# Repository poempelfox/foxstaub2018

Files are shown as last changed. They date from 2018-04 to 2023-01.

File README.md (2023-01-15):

# FoxStaub 2018 - 2022 edition

(FIXME: add picture)

## Introduction

This is a solar powered air quality (fine particles) sensor based on an SDS011
particulate matter (PM) sensor. It also features a BME280 sensor for
measuring temperature, humidity and barometric pressure. An
Adafruit 32U4 RFM69HCW with 868 MHz radio is used as the main microcontroller,
and transmits the measured data wirelessly. The radio-transmitted measurements
are then received by a [Jeelink V3](https://jeelabs.net/projects/hardware/wiki/JeeLink)
and fed into [FHEM](https://fhem.de/).

This project was of course inspired by [https://luftdaten.info](luftdaten.info),
a project for the crowd-sourcing of open sensor data originating in the city of
Stuttgart, which does due to its geography have a very high fine particle
pollution.

## Part list / BOM

* Adafruit Feather 32U4 RFM69HCW (868 MHz variant)
* Adafruit SHT31 (temperature/humidity sensor) breakout
* ClosedCube LPS25HB (pressure sensor) breakout
* Note that the original version of this, built in 2018, used a BME280 instead of the SHT31 and the LPS25HB. After two of these died within just 5 years (after reporting utter nonsense in the weeks or months before), I have decided these are not suitable sensors, and replaced them.
* SDS011 air quality sensor
* JST XH 7pin plug to connect the SDS011.  
  I used Voelkner #D17687 (as the hull of the plug) and #D16379 (as the pins
  inside), and this is the proper plug to use, but alternatively, you should be
  just fine with using normal jumper wire connectors.
* Two "Marley HT" pipe bends are used as the case, as in the luftdaten.info project.  
  However, the DN75 size they recommend wasn't available, so I used DN90 instead.
* 12V AGM battery for storing the power. I originally used a "Offgridtec AGM Solar
  Batterie extrem zyklenfest 12 Ah 12V" off Amazon, but this proved to be too small
  for the winter, always running out of power around December. This has been upgraded
  to a 32 Ah battery in January 2023, we'll see how that one works out.
* (5m) Micro USB power cable for getting the power from the battery to the sensor
* solar charge controller with USB output (I used a "LS0512EU 5A" off Amazon)
* a solar panel big enough to charge the battery even when it's not sunny (I  
  used a "Suaoki Solar Autobatterie Panel Ladegeraet 18W 18V" off Amazon. This  
  is a thin, bendable module that I mounted onto a wooden board for stability.)
* (5m) cable for connecting the solar panel to the charge controller
* fuse to prevent short circuits from making things go up in smoke

## Power

Sadly, the SDS011 uses a lot of power while measuring, the data sheet claims
up to 80 mA. That makes powering this with solar power a challenge, even if it
does not measure continuously (it measures for 30 seconds before going to sleep
for 120 seconds because that increases the sensor life) and actual consumption
seems to be less than what the datasheet claims.

The microcontroller-board actually would have a LiPo charger circuit onboard,
so you could just connect a somewhat large LiPo battery and be done with it
(you'd need to generate the 5V for the SDS011 through a boost converter from
the microcontroller-boards 3.3V output though).
However, I did not like the idea of putting a temperamental LiPo battery into a
tiny case that can heat to 50+ degrees when hit by the sun, and cool below -20
in winter. Instead, the plan was to use a "Goal Zero Guide 10 Plus" power bank
with four NiMH batteries for storing the power. However, it turned out to be
impossible to find any 6V solar panel that would be big enough to charge that
power bank and rigid enough to be mounted on my balcony. It seems solar panels
only come in two flavours: 6V and utter crap (mechanically), or 12+V.

So sadly, instead of the nice and compact power bank,
I had to use a 12V AGM battery and matching solar charge controller with
USB output. These parts are not right where the sensor and the solar panel are,
but instead they're connected by 5 meters of cable and stored safely in the
closet adjacent to my balcony where they are protected from the weather.

## Wireless protocol

Data is sent on 868,300 MHz with FSK modulation and a bitrate of 17241 baud.
On a higher level, the protocol we use is that of a "CustomSensor" from the
FHEM LaCrosseItPlusReader sketch for the Jeelink. However, support for that
if not compiled in by default, so you will have to enable it in the source
code, then recompile the sketch and flash the result onto your Jeelink.

The file `36_Foxstaub2018viaJeelink.pm` in this repository contains the
FHEM module for receiving the sensor. To use it, you will need to put this
file into /opt/fhem/FHEM/ and then modify the file 36_JeeLink.pm: to the
string `clientsJeeLink` append `:Foxstaub2018viaJeelink`.

The format of the packets we send is this:

| Byte | Content description |
| ---: | ---|
| (-)  | Preamble: 3 times 0xAA (you usually don't see these bytes anywhere) |
| (-)  | Sync-Bytes (2): 0x2D 0xD4 |
| 0  | Startbyte (=0xCC) |
| 1  | Sensor-ID (in the range 0 - 255/0xff) |
| 2  | Number of data bytes that follow (13) |
| 3  | Sensortype (=0xf5 for FoxStaub) |
| 4  | Pressure, MSB. Raw value from LPS25HB. |
| 5  | Pressure cont. |
| 6  | Pressure, LSB |
| 7  | Temperature, MSB.  Raw value from SHT31. Formula for converting to degree celsius (value / 65535) * 175 - 45 |
| 8  | Temperature, LSB |
| 9  | rel.Humidity, MSB.  Raw value from SHT31. 0 == 0%, 65535 == 100% |
|  10  | rel.Humidity, LSB |
|  11  | PM2.5, MSB.  Particulate Matter 2.5u is in 1/10th ug/m^3 |
|  12  | PM2.5, LSB |
|  13  | PM10, MSB.  Particulate Matter 10u is in 1/10th ug/m^3 |
|  14  | PM10, LSB |
|  15  | Battery voltage. This is measured through a voltage divider, with 1 MOhm towards GND, and 10 MOhm towards '+'. The ADC runs with a reference voltage of 2.56 volts, meaning 255 would be 2.56 volts, thus the formula for converting this value into volts is: value * 0.11 |
|  16  | CRC |

## Compile error

Compilation of console.c will fail when using an avr-gcc version between
4.8 and 6.4 (inclusive) due to a compiler bug. avr-gcc will die with the
error message `internal compiler error: in push_reload, at reload.c:1360`.
As a workaround, you can add `-fno-move-loop-invariants` to the compiler
flags. Using this just for console.c is enough, for the rest of the source gcc
does not need this workaround.

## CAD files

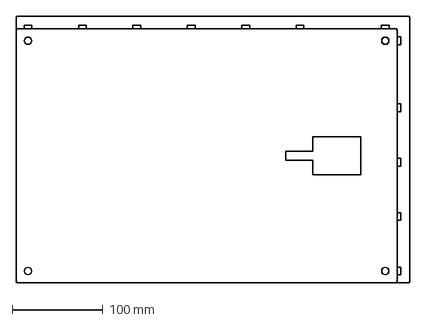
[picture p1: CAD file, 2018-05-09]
solarpanel/solarpanelholder.dxf
434.0 x 294.0 mm

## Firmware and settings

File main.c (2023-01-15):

/* $Id: main.c $
 * main for foxstaub2018 (Foxis Feinstaubsensor)
 * (C) Michael "Fox" Meier 2018
 */

#include <avr/io.h>
#include <avr/interrupt.h>
#include <avr/wdt.h>
#include <avr/eeprom.h>
#include <avr/power.h>
#include <avr/sleep.h>
#include <stdio.h>
#include <string.h>
#include <util/delay.h>

#include "adc.h"
#include "eeprom.h"
#include "lps25hb.h"
#include "lufa/console.h"
#include "rfm69.h"
#include "sds011.h"
#include "sht3x.h"
#include "timers.h"

/* The values last measured */
/* How often did we send a packet? */
uint32_t pktssent = 0;
/* Pressure, in (Pascal * 256) */
uint32_t pressure = 0;
/* Temperature, in (degC * 100) */
int32_t temperature = 0;
/* Rel. Humidity, in (% * 512) */
uint16_t humidity = 0;
/* Particulate matter measurements. in (PMn * 10) ug/m^3 */
/* 0xffff marks it as invalid, this value can never be measured as it's far
 * outside the sensors range */
uint16_t particulatematter2_5u = 0xffff;
uint16_t particulatematter10u = 0xffff;
uint8_t batvolt = 0;

/* This is just a fallback value, in case we cannot read this from EEPROM
 * on Boot */
uint8_t sensorid = 3; // 0 - 255 / 0xff

/* The frame we're preparing to send. */
static uint8_t frametosend[17];

/* Length of one SDS011 measurement cycle, in ticks. */
#define SDS011CYCLELENGTH 72 /* 151 seconds */
/* How long do we turn the sensor on at the beginning of the cycle? */
#define SDS011CYCLEONTIME 15 /* 31 seconds */

/* We need to disable the watchdog very early, because it stays active
 * after a reset with a timeout of only 15 ms. */
void dwdtonreset(void) __attribute__((naked)) __attribute__((section(".init3")));
void dwdtonreset(void) {
  MCUSR = 0;
  wdt_disable();
}

static uint8_t calculatecrc(uint8_t * data, uint8_t len)
{
  uint8_t i, j;
  uint8_t res = 0;
  for (j = 0; j < len; j++) {
    uint8_t val = data[j];
    for (i = 0; i < 8; i++) {
      uint8_t tmp = (uint8_t)((res ^ val) & 0x80);
      res <<= 1;
      if (0 != tmp) {
        res ^= 0x31;
      }
      val <<= 1;
    }
  }
  return res;
}

/* Fill the frame to send with our collected data and a CRC.
 * The protocol we use is that of a "CustomSensor" from the
 * FHEM LaCrosseItPlusReader sketch for the Jeelink.
 * So you'll just have to enable the support for CustomSensor in that sketch
 * and flash it onto a JeeNode and voila, you have your receiver.
 *
 * Byte  0: Startbyte (=0xCC)
 * Byte  1: Sensor-ID (0 - 255/0xff)
 * Byte  2: Number of data bytes that follow (13)
 * Byte  3: Sensortype (=0xf5 for FoxStaub)
 * Byte  4: Pressure, MSB    (raw value from LPS25HB)
 * Byte  5: Pressure
 * Byte  6: Pressure, LSB
 * Byte  7: Temperature, MSB   (raw value from SHT31)
 * Byte  8: Temperature, LSB
 * Byte  9: rel.Humidity, MSB  (raw value from SHT31)
 * Byte 10: rel.Humidity, LSB
 * Byte 11: PM2.5, MSB       particulate matter 2.5 is in 1/10th ug/m^3
 * Byte 12: PM2.5, LSB
 * Byte 13: PM10, MSB
 * Byte 14: PM10, LSB
 * Byte 15: battery voltage
 * Byte 16: CRC
 */
void prepareframe(void)
{
  frametosend[ 0] = 0xCC;
  frametosend[ 1] = sensorid;
  frametosend[ 2] = 13; /* 13 bytes of data follow (CRC not counted) */
  frametosend[ 3] = 0xf5; /* Sensor type: FoxStaub */
  frametosend[ 4] = (pressure >> 16) & 0xff;
  frametosend[ 5] = (pressure >>  8) & 0xff;
  frametosend[ 6] = (pressure >>  0) & 0xff;
  frametosend[ 7] = (temperature >> 8) & 0xff;
  frametosend[ 8] = (temperature >> 0) & 0xff;
  frametosend[ 9] = (humidity >> 8) & 0xff;
  frametosend[10] = (humidity >> 0) & 0xff;
  frametosend[11] = (particulatematter2_5u >> 8) & 0xff;
  frametosend[12] = (particulatematter2_5u >> 0) & 0xff;
  frametosend[13] = (particulatematter10u >> 8) & 0xff;
  frametosend[14] = (particulatematter10u >> 0) & 0xff;
  frametosend[15] = batvolt;
  frametosend[16] = calculatecrc(frametosend, 16);
}

void loadsettingsfromeeprom(void)
{
  uint8_t e1 = eeprom_read_byte(&ee_sensorid);
  uint8_t e2 = eeprom_read_byte(&ee_invsensorid);
  if ((e1 ^ 0xff) == e2) { /* OK, the 'checksum' matches. Use this as our ID */
    sensorid = e1;
  }
}

int main(void)
{
  uint16_t lasttxts = 0xf000; /* This forces an update immediately after start */
  uint16_t sds011cyclestart = 0xffff - (SDS011CYCLELENGTH / 2); /* places us at the end of a cycle */
  uint16_t lastloopts = 0;
  uint16_t curts;
  uint16_t tsdiff;
  uint8_t transmitinterval = 15; /* Transmitinterval in ticks of 2.1s, so 15 = 31s */
  
  /* Initialize stuff */
  
  loadsettingsfromeeprom();
  
  adc_init();
  timers_init();
  console_init();
  rfm69_initport();
  /* The RFM69 needs some time to start up (5 ms according to data sheet, we wait 10 to be sure) */
  _delay_ms(10);
  rfm69_initchip();
  rfm69_setsleep(1);
  sht3x_init();
  lps25hb_init();
  
  /* Enable watchdog timer with a timeout of 8 seconds */
  wdt_enable(WDTO_8S); /* Longest possible on ATmega328P */
  
  /* Disable unused chip parts and ports */
  /* PE6 is the IRQ line from the RFM69. We don't use it. Make sure that pin
   * is tristated on our side (it won't float, the RFM69 pulls it) */
  PORTE &= (uint8_t)~_BV(PE6);
  DDRE &= (uint8_t)~_BV(PE6);
  /* Turn off unused stuff on the AVR via PRR registers */
  /* We don't use Timer0 */
  PRR0 |= _BV(PRTIM0);
  /* We don't use Timer3+4. There seems to be a bug in
   * avr-libc on Ubuntu 16.04, it doesn't define PRTIM4 but instead
   * PRTIM2 for a nonexistant Timer2. Therefore we cannot use the
   * macro and hardcode the correct value. */
  PRR1 |= _BV(/* PRTIM4 */ 4) | _BV(PRTIM3);
  DDRC |= (uint8_t)_BV(PC7); /* PC7 is the LED pin, drive it */
  PORTC &= (uint8_t)~_BV(PC7); /* turn it off. */
  /* Disable digital input registers for ADC pins. We don't use any of
   * the ADC pins for digital input and only use ADC4 for ADC. */
  DIDR0 |= _BV(ADC7D) | _BV(ADC6D) | _BV(ADC5D) | _BV(ADC4D) | _BV(ADC1D) | _BV(ADC0D);
  DIDR2 |= _BV(ADC13D) | _BV(ADC12D) | _BV(ADC11D) | _BV(ADC10D) | _BV(ADC9D) | _BV(ADC8D);

  /* The SDS011 needs a LOT longer to start. So lets sleep for some more
   * time and then try to init it. */
  _delay_ms(2000);
  sds011_init();

  /* Prepare sleep mode */
  /* SLEEP_MODE_IDLE is the only sleepmode we can safely use. */
  set_sleep_mode(SLEEP_MODE_IDLE);
  sleep_enable();

  /* All set up, enable interrupts and go. */
  sei();

  while (1) {
    wdt_reset();
    curts = timers_getticks();
    tsdiff = curts - lasttxts;
    if (tsdiff >= transmitinterval) {
      struct sht3xdata temphum;
      struct lps25hbdata lps25press;
      /* Time to update values and send */
      adc_power(1);
      adc_start();
      sht3x_read(&temphum);
      if (temphum.valid) {
        temperature = temphum.temp;
        humidity = temphum.hum;
      } else {
        temperature = 0xffff;
        humidity = 0xffff;
      }
      /* FIXME add LPS25HB here */
      lps25hb_read(&lps25press);
      if (lps25press.valid) {
        pressure = ((uint32_t)lps25press.pressure[2] << 16)
                 | ((uint32_t)lps25press.pressure[1] <<  8)
                 | lps25press.pressure[0];
      } else {
        pressure = 0xffffff;
      }
      particulatematter2_5u = sds011_getlastpm2_5();
      particulatematter10u = sds011_getlastpm10();
      sht3x_startmeas(); /* Start the next measurement */
      lps25hb_startmeas();
      batvolt = adc_read() >> 2;
      adc_power(0);
      /* SEND */
      rfm69_setsleep(0);  /* This mainly turns on the oscillator again */
      prepareframe();
      console_printpgm_P(PSTR(" TX "));
      rfm69_sendarray(frametosend, 18);
      rfm69_setsleep(1);
      pktssent++;
      lasttxts = curts; /* Remember when we last sent a packet */
      /* We use the lowest two bits of pressure as random noise */
      uint8_t rnd = pressure & 0x00000003;
      if (rnd == 3) {
        transmitinterval = 17;
      } else if (rnd == 0) {
        transmitinterval = 15;
      } else { /* 1 or 2 */
        transmitinterval = 16;
      }
    }
    tsdiff = curts - lastloopts;
    if (tsdiff > 0) { /* OK, we had one tick. (we need to make sure we execute only once per tick!) */
      lastloopts = curts;
      tsdiff = curts - sds011cyclestart;
      if (tsdiff >= SDS011CYCLELENGTH) { /* Cycle over - start again */
        sds011cyclestart = curts;
        sds011_setmeasurements(1);
      } else if (tsdiff == SDS011CYCLEONTIME) {
        sds011_requestresult(); /* Request latest result */
        sds011_setmeasurements(0); /* Then turn off */
      }
    }
    console_work();
    if (!console_isusbconfigured()) {
      /* Don't go to sleep when USB is configured. Because then there is no
       * lack of power, and more importantly, we want the console to feel
       * "snappy" and we can't get that if we sleep for 2 second. */
      wdt_reset(); /* Buy us 8 seconds time because the next IRQ might only arrive in 2 seconds */
      sleep_cpu(); /* Go to sleep until the next IRQ arrives */
    }
  }
}

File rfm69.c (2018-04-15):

/* $Id: rfm69.c $
 * Functions for communication with RF12 module
 *
 * This code was heavily copy+pasted from RFMxx.cpp in the FHEM LaCrosseIT+
 * Jeenode Firmware Code.
 */

#include <avr/io.h>
#include <avr/interrupt.h>
#include <util/delay.h>
#include <math.h>
#include "rfm69.h"
#include "lufa/console.h"

/* Pin mappings:
 *  SS     PB4
 *  MOSI   PB2
 *  MISO   PB3
 *  SCK    PB1
 *  RESET  PD4
 *  OUROWNSS PB0 (not used!)
 */
#define RFMDDR   DDRB
#define RFMPIN   PINB
#define RFMPORT  PORTB

#define RFMPIN_SS    PB4
#define RFMPIN_MOSI  PB2
#define RFMPIN_MISO  PB3
#define RFMPIN_SCK   PB1
#define RFMPIN_OURSS PB0

#define RFM_FREQUENCY 868300UL
#define RFM_DATARATE 17241.0

#define PAYLOADSIZE 64

ISR(INT6_vect)
{
  /* Nothing to do here. */
}

ISR(SPI_STC_vect)
{
  /* Nothing to do here. */
}

/* Note: Internal use only. Does not set the SS pin, the calling function
 * has to do that! */
static uint8_t rfm69_spi8(uint8_t value) {
  SPDR = value;
  /* busy-wait for transmission. this loop spins 4 usec with a 2 MHz SPI clock */
  while (!(SPSR & _BV(SPIF))) { }

  return SPDR;
}

uint16_t rfm69_spi16(uint16_t value) {
  _delay_us(1);
  RFMPORT &= (uint8_t)~_BV(RFMPIN_SS);
  _delay_us(1);
  uint16_t reply = rfm69_spi8(value >> 8) << 8;
  reply |= rfm69_spi8(value & 0xff);
  _delay_us(1);
  RFMPORT |= _BV(RFMPIN_SS);
  _delay_us(1);
  
  return reply;
}

uint8_t rfm69_readreg(uint8_t reg) {
  return rfm69_spi16(((uint16_t)(reg & 0x7f) << 8) | 0x00) & 0xff;
}

static void rfm69_writereg(uint8_t reg, uint8_t val) {
  rfm69_spi16(((uint16_t)(reg | 0x80) << 8) | val);
}

void rfm69_clearfifo(void) {
  /* There is no need for reading / ORing the register here because all
   * bits except the FiFoOverrun-bit we set to clear the FIFO are read-only */
  rfm69_writereg(0x28, (1 << 4)); /* RegIrqFlags2 */
}

void rfm69_settransmitter(uint8_t e) {
  if (e) {
    /* RegOpMode => TRANSMIT */
    rfm69_writereg(0x01, (rfm69_readreg(0x01) & 0xE3) | 0x0C);
  } else {
    /* RegOpMode => STANDBY */
    rfm69_writereg(0x01, (rfm69_readreg(0x01) & 0xE3) | 0x04);
  }
}

void rfm69_setsleep(uint8_t s) {
  if (s) {
    /* RegOpMode => SLEEP */
    rfm69_writereg(0x01, (rfm69_readreg(0x01) & 0xE3) | 0x00);
  } else {
    /* RegOpMode => STANDBY */
    rfm69_writereg(0x01, (rfm69_readreg(0x01) & 0xE3) | 0x04);
    while (!(rfm69_readreg(0x27) & 0x80)) { /* Wait until ready */ }
  }
}

void rfm69_sendarray(uint8_t * data, uint8_t length) {
  /* Set the length of our payload */
  rfm69_writereg(0x38, length);
  rfm69_clearfifo(); /* Clear the FIFO */
  /* Now fill the FIFO. We manually set SS and use spi8 because this
   * is the only "register" that is larger than 8 bits. */
  _delay_us(1);
  RFMPORT &= (uint8_t)~_BV(RFMPIN_SS);
  _delay_us(1);
  rfm69_spi8(0x80); /* Select RegFifo (0x00) for writing (|0x80) */
  for (int i = 0; i < length; i++) {
    rfm69_spi8(data[i]);
  }
  _delay_us(1);
  RFMPORT |= _BV(RFMPIN_SS);
  _delay_us(1);
  /* FIFO has been filled. Tell the RFM69 to send by just turning on the transmitter. */
  rfm69_settransmitter(1);
  /* Wait for transmission to finish, visible in RegIrqFlags2. */
  uint8_t reg28 = 0x00;
  uint16_t maxreps = 10000;
  while (!(reg28 & 0x08)) {
    reg28 = rfm69_readreg(0x28);
    maxreps--;
    if (maxreps == 0) {
      console_printpgm_P(PSTR("![TX TIMED OUT]!"));
      break;
    }
  }
  rfm69_settransmitter(0);
}

void rfm69_initport(void) {
  /* Configure Pins for output / input */
  /* on the feather, the RESET pin of the RFM is connected to PD4. Trigger a
   * reset by pulling the RESET pin HIGH for at least 100us. */
  DDRD |= _BV(PD4);
  PORTD |= _BV(PD4);
  /* Now the rest of the I/O pins */
  RFMDDR |= _BV(RFMPIN_MOSI);
  RFMDDR &= (uint8_t)~_BV(RFMPIN_MISO);
  RFMDDR |= _BV(RFMPIN_SCK);
  RFMDDR |= _BV(RFMPIN_SS);
  /* We do not really use the SS pin of the AVR, but if it were pulled low,
   * the AVR would drop out of master mode! To avoid this, we configure it as
   * output pin. */
  RFMDDR |= _BV(RFMPIN_OURSS);

  RFMPORT |= _BV(RFMPIN_SS);
  
  /* Enable hardware SPI, no need to manually do it.
   * set master mode with rate clk/4 = 2 MHz (maximum of RFM69 is unknown) */
  SPCR = _BV(SPE) | _BV(MSTR);
  SPSR = 0x00; /* To set SPI2X to 0, rest is read-only anyways */
  
  _delay_us(200); /* 100us minimum time the RESET pin needs to be pulled high on the RFM */
  PORTD &= (uint8_t)~_BV(PD4);
}
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

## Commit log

2018-04-21 add more basic infrastructure: TWI (I2C).
2018-04-21 make it compile (still doesn't do anything useful)
    [main.c]
2018-04-21 add functions for the BME280 temp/hum/pressure sensor.
2018-04-21 fetch and print temp/hum/pressure.
2018-04-22 also print the raw hex values for temp/press/hum
2018-04-23 change default sensor id
2018-04-23 query fine particle sensor, send packets with all data.
2018-04-23 also print particle measurements
2018-05-02 change unit for humidity to % * 512 instead of % * 1024, because surprisingly "102400" does not fit into 16 bits...
    [main.c]
2018-05-02 fix unit of humidity, always print pm_ values with 1 digit after the comma.
2018-05-09 piece of 5 mm HDF to mount a "Suaoki Solar Autobatterie Panel Ladegeraet 18W 18V Solarzelle" solar panel from amazon to my balcony
    [solarpanelholder.dxf]
2018-06-22 more info about the solar power supply
2021-03-28 set I2C-address to 0x76 the BME280-module that I originally used was configured to address 0x77 by default. After it died I got a different one, which was configured to 0x76.
2023-01-14 Because the BME280 died yet again, we're modifying our sensor a bit: The BME280 gets thrown out and replaced by SHT31 and LPS25HB, and we try to measure the battery voltage.
    [adc.c, lps25hb.c, main.c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]
2023-01-15 do not use humidity 0xffff to detect invalidity, it is a perfectly valid '100%'. Instead assume humidity is valid if temperature is valid.
